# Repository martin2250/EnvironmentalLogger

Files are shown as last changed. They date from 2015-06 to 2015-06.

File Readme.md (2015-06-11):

##Environmental Data Logger

The design files and the software for a small low-power temperature and humidity logger  
Probably the most remarkable feature is the power consumption of just 3.2µA or less
  
a better documentation can be found on [Hackaday.io](https://hackaday.io/project/6177-low-power-environmental-data-logger)  
  
Credits:  
-HD44780 Library by [SA Development](http://www.avrfreaks.net/projects/hd44780-library)  
-I²C Library by [Peter Fleury](http://jump.to/fleury)

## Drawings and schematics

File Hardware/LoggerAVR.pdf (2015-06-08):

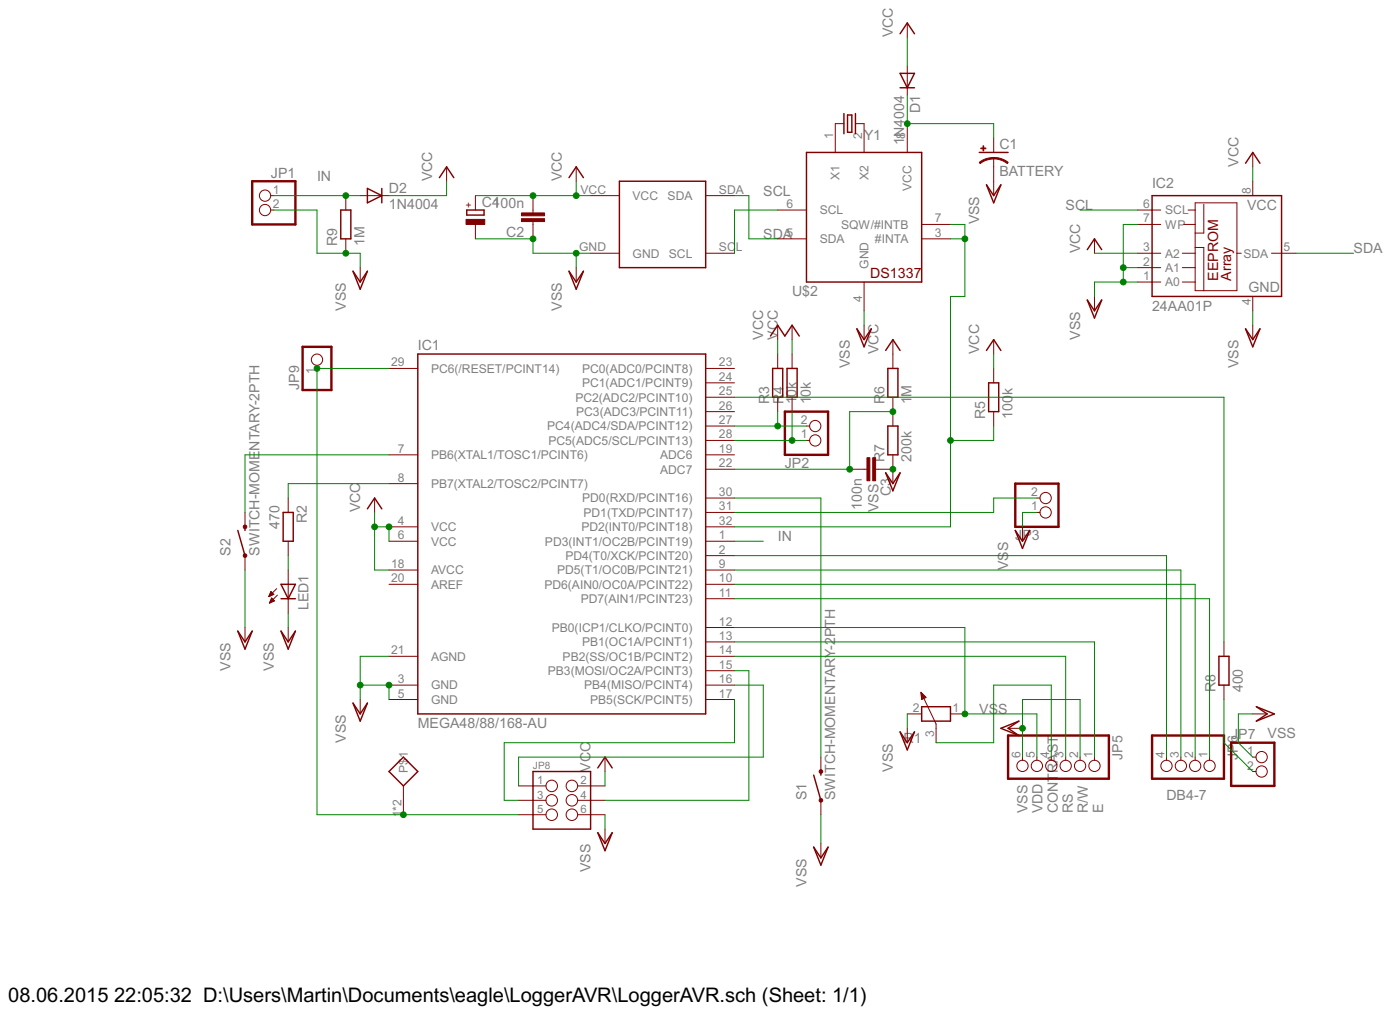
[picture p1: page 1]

08.06.2015 22:05:32 D:\Users\Martin\Documents\eagle\LoggerAVR\LoggerAVR.sch (Sheet: 1/1)

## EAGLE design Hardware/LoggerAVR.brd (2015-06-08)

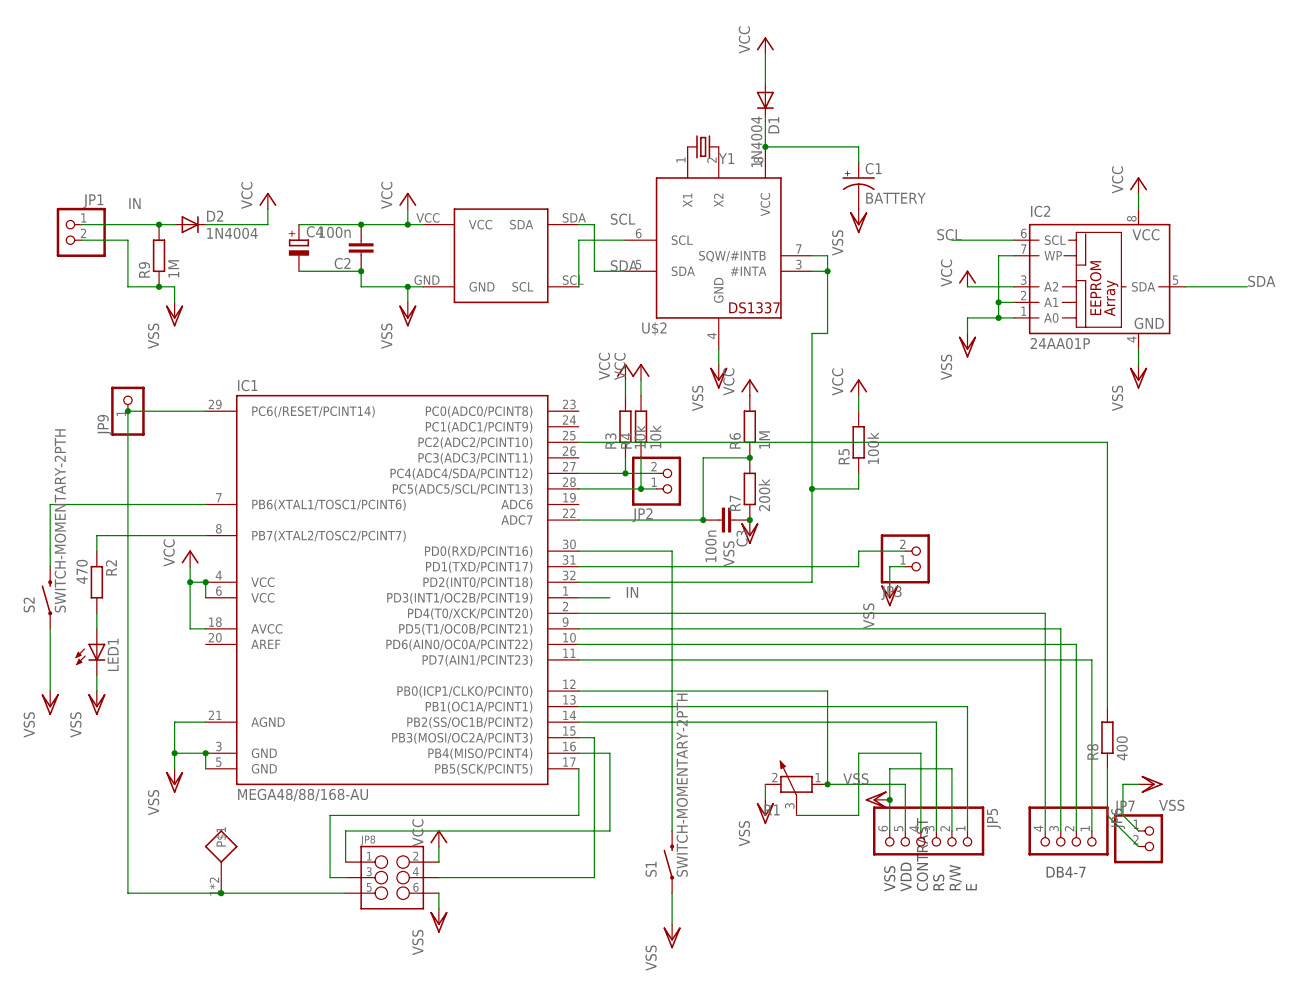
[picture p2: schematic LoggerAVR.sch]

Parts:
C1: BATTERY; ETR2
C2, C3: 100n; C1206
C4: CPOL-EUE22-9AXIAL; E22-9
D1, D2: 1N4004; DO41-10
IC1: MEGA48/88/168-AU; TQFP32-08
IC2: 24AA01P; DIL8
JP1, JP2, JP3, JP7: PINHD-1X2; 1X02
JP5: PINHD-1X6; 1X06
JP6: PINHD-1X4; 1X04
JP8: M03X2SHROUD; 2X3-SHROUDED
JP9: PINHD-1X1; 1X01
LED1: LEDSML1206; SML1206
R1: POTENTIOMETER_PT-10; PT-10
R2: 470; M1206
R3, R4: 10k; M1206
R5: 100k; M1206
R6, R9: 1M; M1206
R7: 200k; M1206
R8: 400; M1206
S1, S2: SWITCH-MOMENTARY-2PTH; TACTILE-PTH
U$1: HYT939; TO39
U$2: DS1337; DIL08-ROUND
U$3: 0 - Jump; R1206
Y1: CRYSTAL32-SMD; CRYSTAL-32KHZ-SMD

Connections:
IN: D2.A, IC1.1 (PD3(INT1/OC2B/PCINT19)), JP1.1, R9.2
unnamed: IC1.2 (PD4(T0/XCK/PCINT20)), JP6.4
unnamed: IC1.30 (PD0(RXD/PCINT16)), S1.3 (2), S1.4 (2)
unnamed: IC1.9 (PD5(T1/OC0B/PCINT21)), JP6.3
unnamed: IC1.15 (PB3(MOSI/OC2A/PCINT3)), JP8.4
unnamed: IC1.16 (PB4(MISO/PCINT4)), JP8.1
unnamed: IC1.17 (PB5(SCK/PCINT5)), JP8.3
unnamed: IC1.29 (PC6(/RESET/PCINT14)), JP8.5, JP9.1, U$3.1, U$3.2
unnamed: IC1.10 (PD6(AIN0/OC0A/PCINT22)), JP6.2
unnamed: U$2.2 (X2), Y1.X2 (2)
unnamed: JP5.4, R1.3
unnamed: IC1.11 (PD7(AIN1/PCINT23)), JP6.1
unnamed: IC1.13 (PB1(OC1A/PCINT1)), JP5.1
unnamed: IC1.14 (PB2(SS/OC1B/PCINT2)), JP5.3
unnamed: IC1.31 (PD1(TXD/PCINT17)), JP3.2
unnamed: IC1.7 (PB6(XTAL1/TOSC1/PCINT6)), S2.3 (2), S2.4 (2)
unnamed: IC1.12 (PB0(ICP1/CLKO/PCINT0)), JP5.5, R1.1
unnamed: U$2.1 (X1), Y1.X1 (1)
unnamed: IC1.32 (PD2(INT0/PCINT18)), R5.1, U$2.3 (#INTA), U$2.7 (SQW/#INTB)
unnamed: IC1.8 (PB7(XTAL2/TOSC2/PCINT7)), R2.1
unnamed: LED1.A, R2.2
unnamed: C3.2, IC1.22 (ADC7), R6.1, R7.2
unnamed: C1.+, D1.C, U$2.8 (VCC)
unnamed: IC1.25 (PC2(ADC2/PCINT10)), R8.2
unnamed: JP7.2, R8.1
SCL: IC1.28 (PC5(ADC5/SCL/PCINT13)), IC2.6 (SCL), JP2.1, R4.1, U$1.SCL, U$2.6 (SCL)
SDA: IC1.27 (PC4(ADC4/SDA/PCINT12)), IC2.5 (SDA), JP2.2, R3.1, U$1.SDA, U$2.5 (SDA)
VCC: C2.2, C4.+, D1.A, D2.C, IC1.4 (VCC), IC1.6 (VCC), IC1.18 (AVCC), IC2.3 (A2), IC2.8 (VCC), JP8.2, R3.2, R4.2, R5.2, R6.2, U$1.VCC
VSS: C1.-, C2.1, C3.1, C4.-, IC1.3 (GND), IC1.5 (GND), IC1.21 (AGND), IC2.1 (A0), IC2.2 (A1), IC2.4 (GND), IC2.7 (WP), JP1.2, JP3.1, JP5.2, JP5.6, JP7.1, JP8.6, LED1.C, R1.2, R7.1, R9.1, S1.1, S1.2 (1), S2.1, S2.2 (1), U$1.GND, U$2.4 (GND)

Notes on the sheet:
DB4-7
VSS VDD CONTRAST RS R/W E

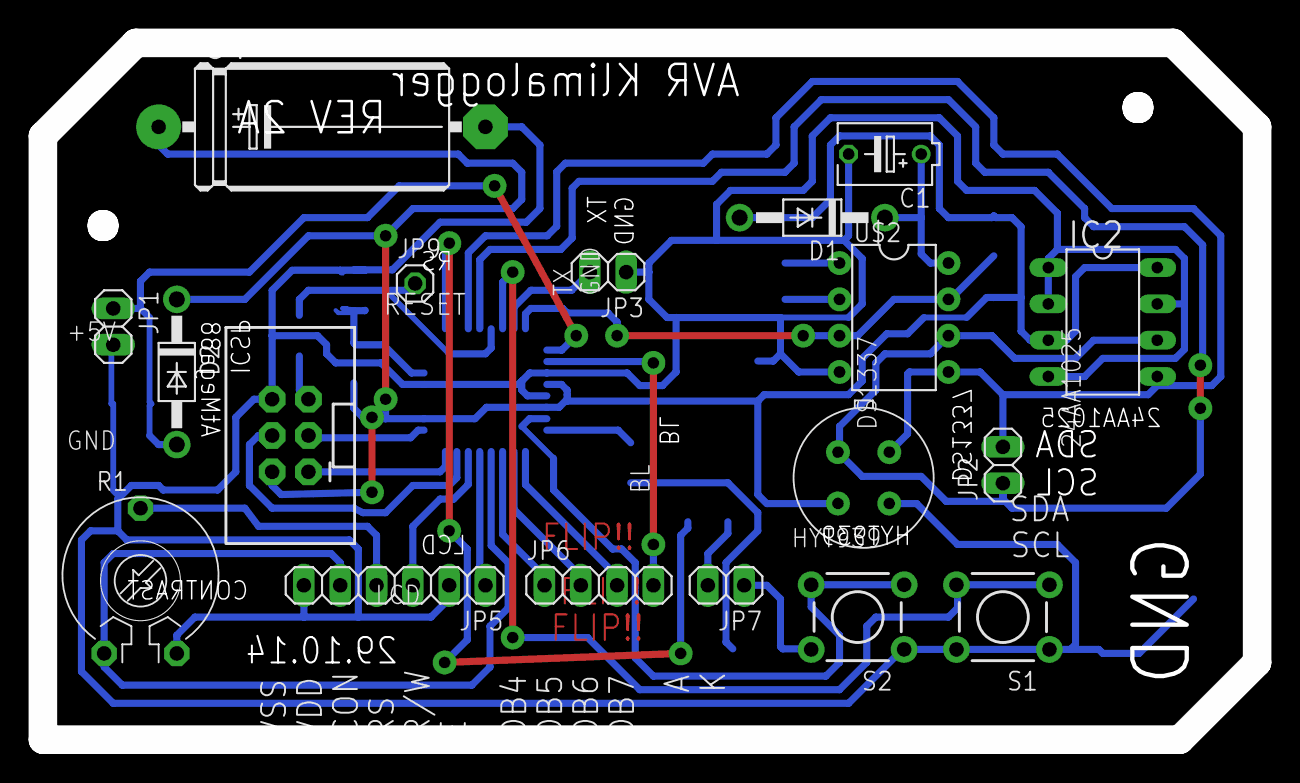
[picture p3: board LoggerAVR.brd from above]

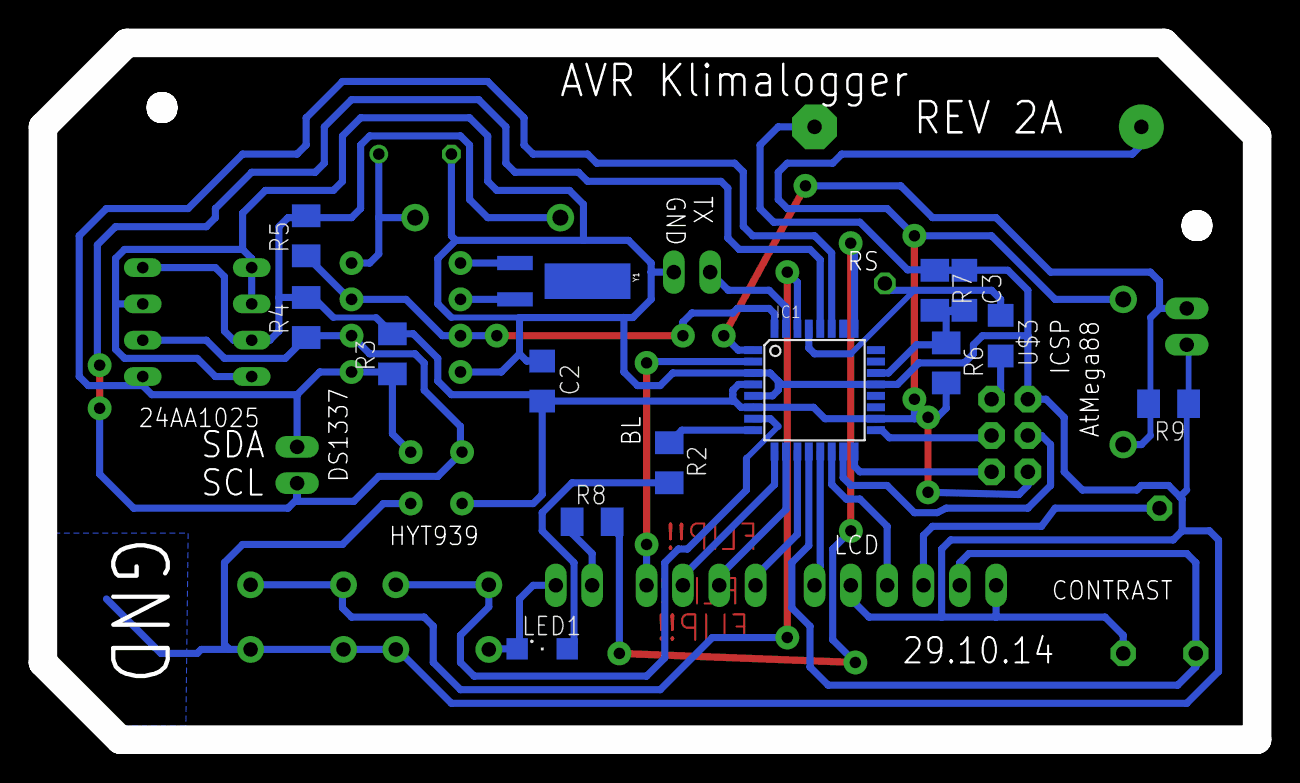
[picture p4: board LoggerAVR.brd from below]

Board: 2 copper layers, 84.9 x 48.7 mm, 32 parts (14 on the bottom side), 29 nets.

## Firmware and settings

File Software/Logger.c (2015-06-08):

/*
* Logger.c
*
* Created: 20.10.2014 20:54:14
*  Author: Martin
*/
#include "defines.h"

#include <avr/io.h>
#include <avr/interrupt.h>
#include <avr/sleep.h>
#include <util/delay.h>
#include <avr/power.h>

#include "lib/hd44780.h"
#include "lib/i2cmaster.h"
#include "util.h"
#include "menu.h"
#include "global.h"
#include "time.h"
#include "sendData.h"
#include "HYT939.h"
#include "showStatus.h"
#include "logging.h"


int main(void)
{
	cli();
	
	setupIO();
	
	sei();
	
	uint8_t TimeToNextMeasurement = IntervalMin;
	uint8_t DisplayTime = DisplayTimeoutMin;
	
	while(1)
	{
		//RTC 1 Min ALarm
		#pragma region RTC 1 Min ALarm

		if(Status.RTCAlarm)
		{
			if(Status.LCD_On)
			{				
				if(DisplayTime == 0)
				{
					Status.LCD_On = 0;
					CurrentButtonHandler = LCDOffBtnHandler;
				}
				
				DisplayTime--;
			}
			
			i2c_start(I2C_WRITE(DS1337));
			i2c_write(0xf);
			i2c_write(0);
			i2c_stop();
			
			if(LoggingEnabled && --TimeToNextMeasurement == 0)
			{
				TimeToNextMeasurement = IntervalMin;
				HYT_request();
				CurrentMeasurementHandlers.Measure = 1;
				
				if(CurrentPageBuffer[0] == 40)
				{
					StorePage();
				}
			}
			
			Status.RTCAlarm = 0;
		}
		
		#pragma endregion RTC 1 Min ALarm
		
		//Measurement Completed
		#pragma region Measurement Completed
		
		if(Status.MeasurementDone)
		{
			Status.MeasurementDone = 0;
			
			HYT_read();
			
			if(CurrentMeasurementHandlers.Measure)
			{
				AddMeasurement();
			}
			if(CurrentMeasurementHandlers.ShowStatus)
			{
				StatusAddMeasurements();
			}
			
			CurrentMeasurementHandlers.Measure = 0;
			CurrentMeasurementHandlers.ShowStatus = 0;
		}
		
		#pragma endregion Measurement Completed
		
		//Buttons
		#pragma region Buttons

		if(Status.Buttons)
		{
			DisplayTime = DisplayTimeoutMin;
			
			if(!Status.LCD_On)
			{
				lcd_init();
				Status.LCD_On = 1;
			}
			
			CurrentButtonHandler();
		
			Status.Buttons = 0;
		}
		
		#pragma endregion Buttons
		
		if(Status.LoadTransmitBuffer)
		{
			NextPage();
		}
		
		if(!Status.LCD_On)
			lcd_off();
		
		TimeUpToDate = 0;
		
		if(Status.Timer1Active | Status.Transmitting)
		{
			set_sleep_mode(SLEEP_MODE_IDLE);
			sleep_mode();
		}
		else
		{
			power_all_disable();
						
			set_sleep_mode(SLEEP_MODE_PWR_DOWN);
			sleep_mode();
		}
	}
}

ISR(INT0_vect) //RTC
{
	Status.RTCAlarm = 1;
}

ISR(INT1_vect)	//power loss
{
	
}

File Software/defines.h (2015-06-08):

/*
 * defines.h
 *
 * Created: 23.10.2014 17:10:00
 *  Author: Martin
 */ 


#ifndef DEFINES_H_
#define DEFINES_H_

#ifndef F_CPU
	#define F_CPU 8000000UL
#endif

#define DS1337 0x68
#define EEPROM_LOW 0x50
#define EEPROM_HIGH 0x54
#define HYT939 0x28

#define ON PORTB |= _BV(7);
#define OFF PORTB &= ~_BV(7);

#define ButtonR 2
#define	ButtonL 1

#define Timer1TCCRB (_BV(CS11) | _BV(CS10)) //64 prescaler -> 128ms bei OCR1A = 16k
#define Timer0TCCRB (_BV(CS02) | _BV(CS00))

typedef void (*funcPtr)(void);
typedef void (*charFuncPtr)(char*);


#define NextPageAddress (((uint16_t*)0) + 2)
#define IntervalMinAddress (((uint16_t*)0) + 3)
#define DisplayTimeoutAddress (((uint16_t*)0) + 4)
#define LoggingEnabledAddress (((uint16_t*)0) + 5)

#endif /* DEFINES_H_ */

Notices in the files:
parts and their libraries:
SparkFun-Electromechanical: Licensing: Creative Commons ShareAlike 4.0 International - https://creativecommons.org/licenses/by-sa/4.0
